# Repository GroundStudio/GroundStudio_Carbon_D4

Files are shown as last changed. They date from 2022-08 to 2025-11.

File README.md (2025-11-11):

GroundStudio Carbon D4
====================================
CarbonD4 cropat la 150 h (https://ardushop.ro/ro/home/2059-placa-de-dezvoltare-carbon-d4.html)

Get it from [ardushop.ro](https://ardushop.ro/en/electronics/1186-placa-de-dezvoltare-carbon-d4-6427854000408.html)

Explore all the GroundStudio products at [ardushop.ro](https://ardushop.ro/en/37-groundstudio)

Description
-------------------
Features ESP32 based Pico D4 SiP with 2.4GHz Wifi, V4.2 Bluetooth, 8MB external SPI PSRAM, 520kB internal SRAM, 448kB ROM, 14 GPIO, 8 ADC and 6 touch sensitive pins, I²C 3V3 adapter, RGB smart LED, 1 cell LiPo/LiIon battery charger with optional battery connector and CH340C for USB comunication.

Contents
-------------------

* [/Documentation](https://github.com/GroundStudio/GroundStudio_Carbon_D4/tree/main/Documentation) -- Pinout.
* [/Hardware](https://github.com/GroundStudio/GroundStudio_Carbon_D4/tree/main/Hardware) -- Schematics, layout.

Versions
-------------------
*(Not all tags shown)*

* [REV0.0.2]
  * added testpoint for GPIO0
  * R16 and R17 connected in series
  * interchanged GPIO2 and GPIO12 functions because GPIO12 cannot be pulled high while in flash mode
  * added 100nF in parallel with R13 for better battery voltage level reading
  * adjusted the pin labels for better visibility

License
-------------------

This is released under the [Attribution-ShareAlike 4.0 International (CC BY-SA 4.0)](https://creativecommons.org/licenses/by-sa/4.0/) license. 
**You are welcome to use this for commercial purposes.**

Please consider contributing back to this project or others to help the open-source hardware community continue to thrive and grow! 

Certifications:

[Open Source Hardware Association](https://certification.oshwa.org/ro000006.html)   
   
certification-mark-RO000006-wide (https://certification.oshwa.org/ro000006.html)

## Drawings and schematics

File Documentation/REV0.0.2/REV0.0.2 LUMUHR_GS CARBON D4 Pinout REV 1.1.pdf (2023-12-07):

# GroundStudio Carbon D4

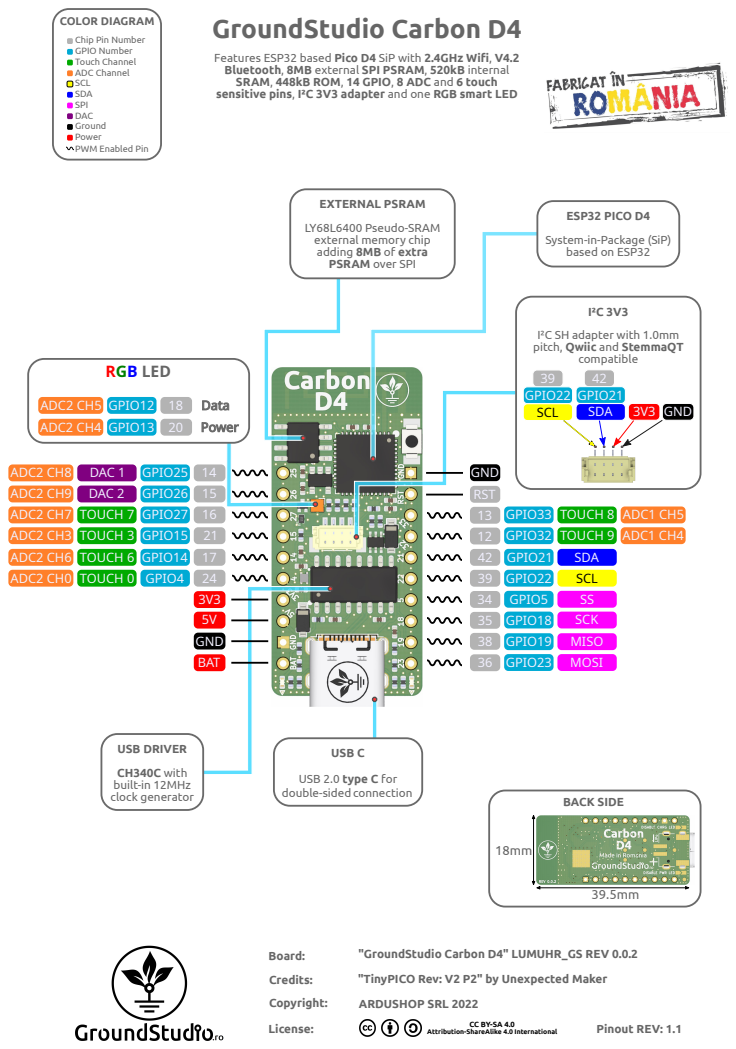
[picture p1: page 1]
COLOR DIAGRAM; GND RST 13 12 42 39 34 35 38 36; GPIO33 GPIO32 GPIO21 GPIO22 GPIO5 GPIO18 GPIO19 GPIO23; TOUCH 8 TOUCH 9 SDA SCL SS SCK MISO MOSI; ADC1 CH5 ADC1 CH4; USB DRIVER; CH340C with built-in 12MHz clock generator; GND BAT; GPIO25 GPIO26 GPIO27 GPIO15 GPIO14; DAC 1 DAC 2 TOUCH 7 TOUCH 3 TOUCH 6; ADC2 CH8 ADC2 CH9 ADC2 CH7 ADC2 CH3 ADC2 CH6; RGB LED; Data Power; ADC2 CH5 GPIO12 18 ADC2 CH4 GPIO13 20; ADC2 CH0 TOUCH 0 GPIO4 24; GND; SCL; I²C 3V3; compatible; USB C; BACK SIDE; Copyright: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

Chip Pin Number
GPIO Number
Touch Channel
ADC Channel
SCL
SDA
SPI
DAC
Ground
Power
PWM Enabled Pin

Features ESP32 based Pico D4 SiP with 2.4GHz Wifi, V4.2
Bluetooth, 8MB external SPI PSRAM, 520kB internal
SRAM, 448kB ROM, 14 GPIO, 8 ADC and 6 touch
sensitive pins, I²C 3V3 adapter and one RGB smart LED

EXTERNAL PSRAM
LY68L6400 Pseudo-SRAM
external memory chip
adding 8MB of extra
PSRAM over SPI

ESP32 PICO D4
System-in-Package (SiP)
based on ESP32

I²C SH adapter with 1.0mm
pitch, Qwiic and StemmaQT
GPIO21
GPIO22

USB 2.0 type C for
double-sided connection

"GroundStudio Carbon D4" LUMUHR_GS REV 0.0.2

Attribution-ShareAlike 4.0 International

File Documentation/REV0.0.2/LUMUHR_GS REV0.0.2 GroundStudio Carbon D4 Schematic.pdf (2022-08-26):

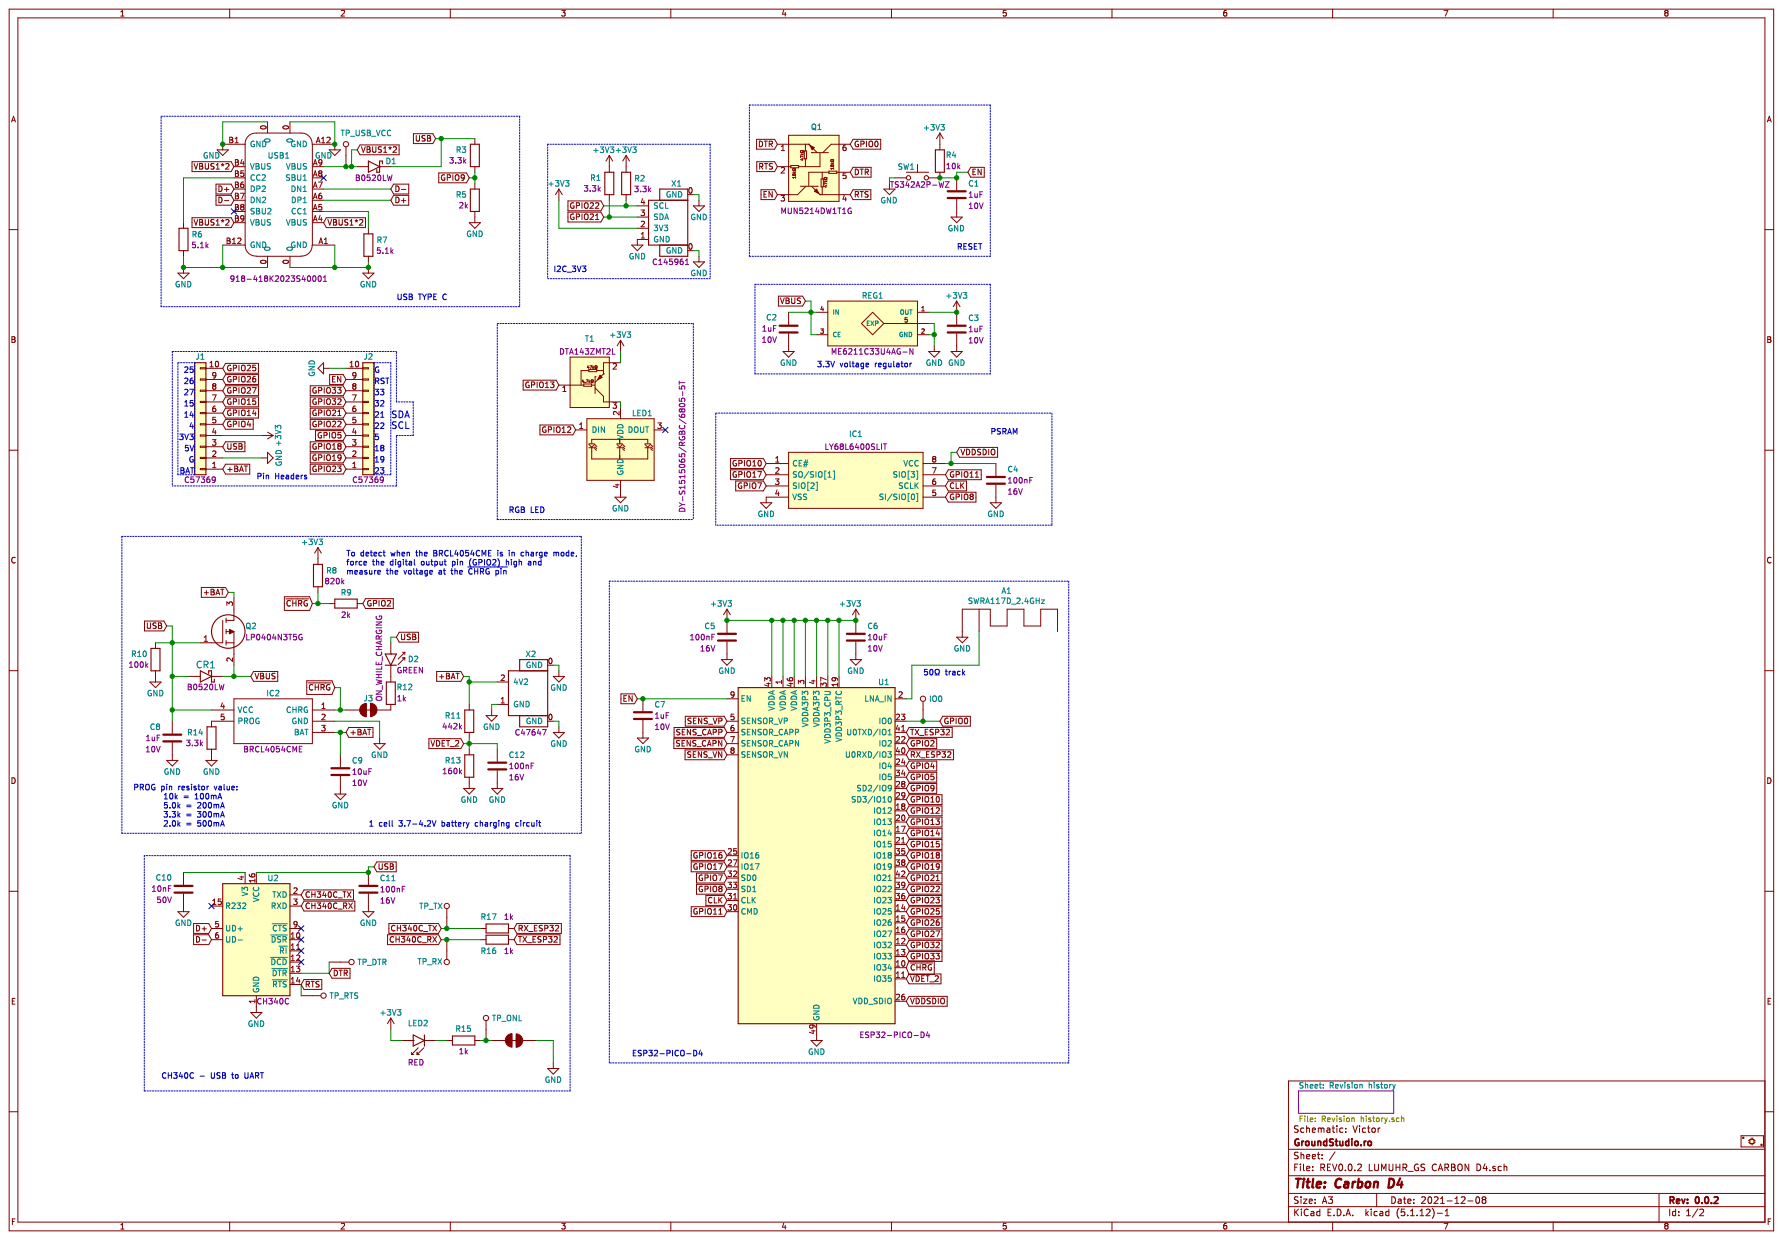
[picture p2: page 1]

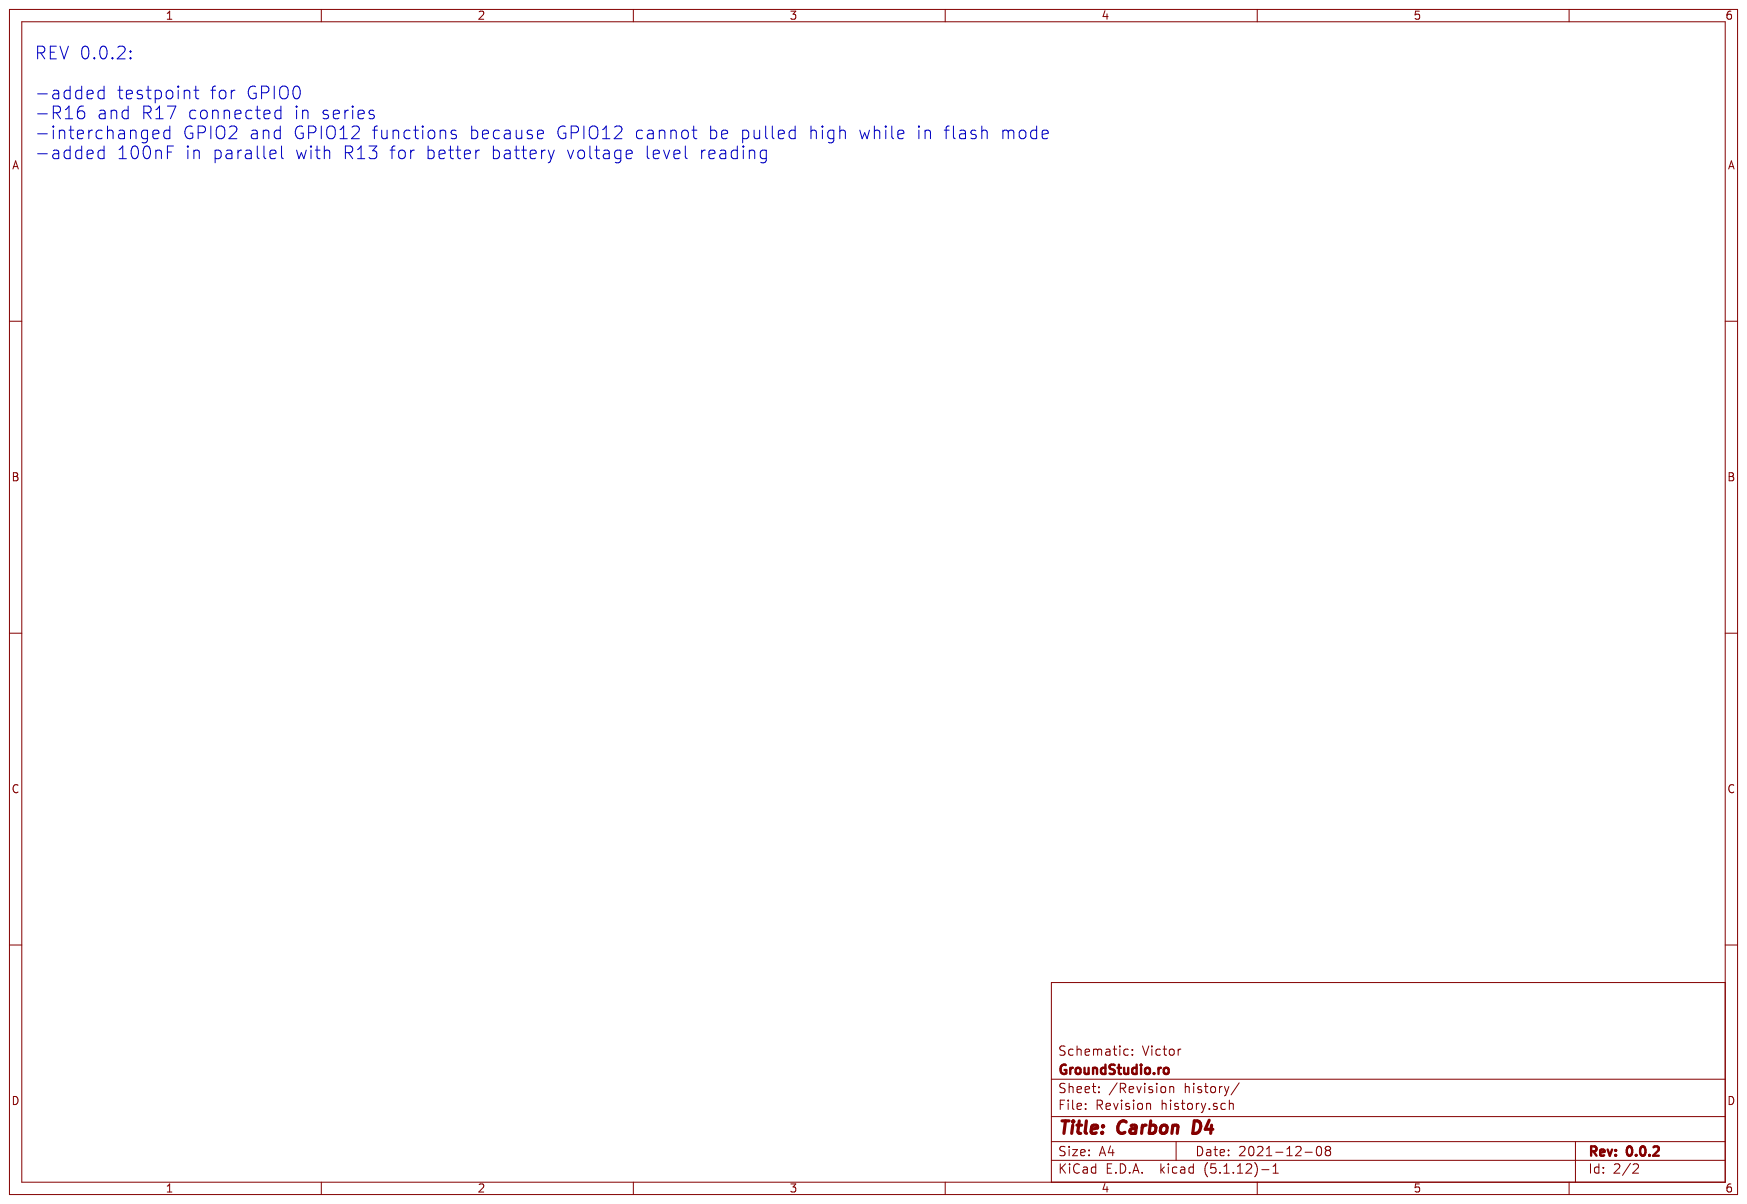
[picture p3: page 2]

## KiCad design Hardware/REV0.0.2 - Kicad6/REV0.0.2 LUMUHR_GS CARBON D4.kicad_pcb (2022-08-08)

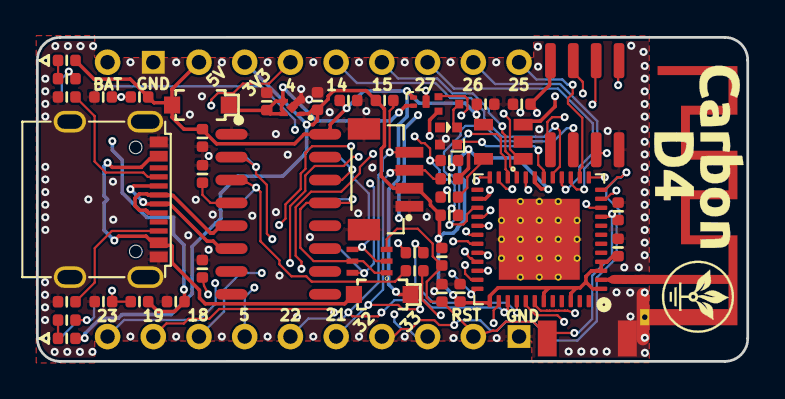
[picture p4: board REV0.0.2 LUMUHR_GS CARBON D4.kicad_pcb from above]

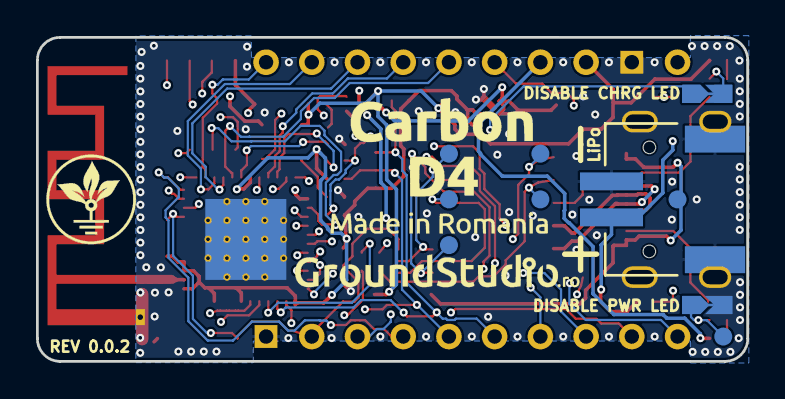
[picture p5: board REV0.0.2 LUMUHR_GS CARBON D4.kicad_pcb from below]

Board: 4 copper layers, 39.5 x 18.0 mm, 58 parts (5 on the bottom side), 53 nets.

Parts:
A1: SWRA117D_2.4GHz; Texas_SWRA117D_2.4GHz_Left
C1, C2, C3, C7, C8: C_0402_1uF_10V; C_0402_alt
C4, C5, C11, C12: C_0402_100nF_16V; C_0402_alt
C6, C9: C_0402_10uF_10V; C_0402_alt
C10: C_0402_10nF_50V; C_0402_alt
CR1: SOD-123 B0520LW; SOD-123
D1: SOD-123 B0520LW; SOD-123
D2: LED_0402_GREEN; LED_0402_alt
IC1: SOIC-8_3.9x4.9 LY68L6400SLIT; SOIC-8_3.9x4.9mm_P1.27mm
IC2: SOT23-5 BRCL4054CME; SOT-23-5
J1, J2: PinHeader_1x10_P2.54_V_M C57369; PinHeader_1x10_P2.54mm_Vertical_Male
J3: disable CHARGING LED; SolderJumper_NC
J4: PWR LED DISABLE; SolderJumper_NC
LED1: SK6805-EC15 DY-S1515065; SK6805-EC15
LED2: LED_0402_RED; LED_0402_alt
Q1: SOT-363 MUN5214DW1T1G; SOT-363
Q2: SOT-883 LP0404N3T5G; SOT-883
R1, R2, R3, R14: R_0402_3.3k; R_0402_alt
R4: R_0402_alt 0402WGJ0103TCE; R_0402_alt
R5, R9: R_0402_2k; R_0402_alt
R6, R7: R_0402_5.1k; R_0402_alt
R8: R_0402_820k; R_0402_alt
R10: R_0402_100k; R_0402_alt
R11: R_0402_442k; R_0402_alt
R12, R15, R16, R17: R_0402_1k; R_0402_alt
R13: R_0402_160k; R_0402_alt
REG1: FBP1-1-4_ME6211C33U4AG-N; FBP1-1-4
SW1: TS342A2P-WZ
T1: SOT-723_DTA143ZMT2L; SOT-723
TP1: TP_USB_VCC; TestPoint
TP2: TP_DTR; TestPoint
TP3: TP_TX; TestPoint
TP4: TP_RTS; TestPoint
TP5: TP_ONL; TestPoint
TP6: TP_RX; TestPoint
TP7: IO0; TestPoint
U1: QFN-48-7x7 ESP32-D4; QFN-48-1EP_7x7mm_P0.5mm_EP4.5x4.5mm
U2: SOP-16_150MIL CH340C; SOP-16_150MIL
USB1: USB_C_C167321 C167321; USB_C_C167321
X1: SH__1x04_Vertical C145961; SH__1x04_P1.00mm_Vertical
X2: PH__1x02_P2.00mm_Horizontal C47647; PH__1x02_P2.00mm_Horizontal

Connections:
+3V3: C3.1, C5.1, C6.1, J1.4, LED2.2, R1.2, R2.1, R4.2, R8.1, REG1.1, T1.2, U1.1, U1.3, U1.4, U1.19, U1.37, U1.43, U1.46, X1.2
+BAT: C9.1, IC2.3, J1.1, Q2.3, R11.2, X2.2
CH340C_RX: R16.1, TP6.~, U2.3
CH340C_TX: R17.1, TP3.~, U2.2
CLK: IC1.6, U1.31
D+: U2.5, USB1.A6, USB1.B6
D-: U2.6, USB1.A7, USB1.B7
DTR: Q1.1, Q1.5, TP2.~, U2.13
EN: C1.1, C7.1, J2.9, Q1.3, R4.1, SW1.2, U1.9
Feed: A1.1, U1.2
GND: A1.2, C1.2, C2.1, C3.2, C4.2, C5.2, C6.2, C7.2, C8.2, C9.2, C10.1, C11.2, C12.2, IC1.4, IC2.2, J1.2, J2.10, J4.2, LED1.4, R5.1, R6.2, R7.2, R10.1, R13.1, R14.1, REG1.2, REG1.5, SW1.1, U1.49, U2.1, USB1.0, USB1.A1, USB1.A12, USB1.B1, USB1.B12, X1.0, X1.1, X2.0, X2.1
GPIO0: Q1.6, TP7.~, U1.23
GPIO2: R9.2, U1.22
GPIO4: J1.5, U1.24
GPIO5: J2.4, U1.34
GPIO7: IC1.3, U1.32
GPIO8: IC1.5, U1.33
GPIO9: R3.1, R5.2, U1.28
GPIO10: IC1.1, U1.29
GPIO11: IC1.7, U1.30
GPIO12: LED1.1, U1.18
GPIO13: T1.1, U1.20
GPIO14: J1.6, U1.17
GPIO15: J1.7, U1.21
GPIO17: IC1.2, U1.27
GPIO18: J2.3, U1.35
GPIO19: J2.2, U1.38
GPIO21: J2.6, R1.1, U1.42, X1.3
GPIO22: J2.5, R2.2, U1.39, X1.4
GPIO23: J2.1, U1.36
GPIO25: J1.10, U1.14
GPIO26: J1.9, U1.15
GPIO27: J1.8, U1.16
GPIO32: J2.7, U1.12
GPIO33: J2.8, U1.13
unnamed: C10.2, U2.4
unnamed: D2.1, R12.2
unnamed: IC2.5, R14.2
unnamed: J3.2, R12.1
unnamed: J4.1, R15.2, TP5.~
unnamed: LED1.2, T1.3
unnamed: LED2.1, R15.1
unnamed: R6.1, USB1.B5
unnamed: R7.1, USB1.A5
RTS: Q1.2, Q1.4, TP4.~, U2.14
RX_ESP32: R17.2, U1.40
TX_ESP32: R16.2, U1.41
USB: C8.1, C11.1, CR1.2, D1.1, D2.2, IC2.4, J1.3, Q2.1, R3.2, R10.2, U2.16
VBUS: C2.2, CR1.1, Q2.2, REG1.3, REG1.4
VBUS1*2: D1.2, TP1.~, USB1.A4, USB1.A9, USB1.B4, USB1.B9
VDDSDIO: C4.1, IC1.8, U1.26
VDET_2: C12.1, R11.1, R13.2, U1.11
~CHRG: IC2.1, J3.1, R8.2, R9.1, U1.10

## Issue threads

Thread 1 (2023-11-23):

Question: How to measure battery voltage

alexandru-g, 2023-11-23:
Hello! Is there any way we can measure the connected cell's voltage / state of charge? Thank you!

victor1115, 2023-12-21:
Hi Alexandru,

Cell's voltage can be read using IO35 pin of the ESP32-PICO-D4.
The analog value need to be calibrated to consider the voltage divider between +BAT and GND so that it show the right voltage.

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

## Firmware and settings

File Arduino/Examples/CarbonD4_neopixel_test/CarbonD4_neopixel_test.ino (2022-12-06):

// A basic everyday NeoPixel strip test program.

// NEOPIXEL BEST PRACTICES for most reliable operation:
// - Add 1000 uF CAPACITOR between NeoPixel strip's + and - connections.
// - MINIMIZE WIRING LENGTH between microcontroller board and first pixel.
// - NeoPixel strip's DATA-IN should pass through a 300-500 OHM RESISTOR.
// - AVOID connecting NeoPixels on a LIVE CIRCUIT. If you must, ALWAYS
//   connect GROUND (-) first, then +, then data.
// - When using a 3.3V microcontroller with a 5V-powered NeoPixel strip,
//   a LOGIC-LEVEL CONVERTER on the data line is STRONGLY RECOMMENDED.
// (Skipping these may work OK on your workbench but can fail in the field)

#include <Adafruit_NeoPixel.h>
#ifdef __AVR__
 #include <avr/power.h> // Required for 16 MHz Adafruit Trinket
#endif

// Which pin on the Arduino is connected to the NeoPixels?
// On a Trinket or Gemma we suggest changing this to 1:
#define LED_PIN    12
#define LED_ENABLE_PIN 13

// How many NeoPixels are attached to the Arduino?
#define LED_COUNT 1

// Declare our NeoPixel strip object:
Adafruit_NeoPixel strip(LED_COUNT, LED_PIN, NEO_GRB + NEO_KHZ800);
// Argument 1 = Number of pixels in NeoPixel strip
// Argument 2 = Arduino pin number (most are valid)
// Argument 3 = Pixel type flags, add together as needed:
//   NEO_KHZ800  800 KHz bitstream (most NeoPixel products w/WS2812 LEDs)
//   NEO_KHZ400  400 KHz (classic 'v1' (not v2) FLORA pixels, WS2811 drivers)
//   NEO_GRB     Pixels are wired for GRB bitstream (most NeoPixel products)
//   NEO_RGB     Pixels are wired for RGB bitstream (v1 FLORA pixels, not v2)
//   NEO_RGBW    Pixels are wired for RGBW bitstream (NeoPixel RGBW products)


// setup() function -- runs once at startup --------------------------------

void setup() {
  pinMode(LED_ENABLE_PIN, OUTPUT);
  digitalWrite(LED_ENABLE_PIN, 0);
  // These lines are specifically to support the Adafruit Trinket 5V 16 MHz.
  // Any other board, you can remove this part (but no harm leaving it):
#if defined(__AVR_ATtiny85__) && (F_CPU == 16000000)
  clock_prescale_set(clock_div_1);
#endif
  // END of Trinket-specific code.

  strip.begin();           // INITIALIZE NeoPixel strip object (REQUIRED)
  strip.show();            // Turn OFF all pixels ASAP
  strip.setBrightness(50); // Set BRIGHTNESS to about 1/5 (max = 255)
}


// loop() function -- runs repeatedly as long as board is on ---------------

void loop() {
  // Fill along the length of the strip in various colors...
  colorWipe(strip.Color(255,   0,   0), 50); // Red
  colorWipe(strip.Color(  0, 255,   0), 50); // Green
  colorWipe(strip.Color(  0,   0, 255), 50); // Blue

  // Do a theater marquee effect in various colors...
  theaterChase(strip.Color(127, 127, 127), 50); // White, half brightness
  theaterChase(strip.Color(127,   0,   0), 50); // Red, half brightness
  theaterChase(strip.Color(  0,   0, 127), 50); // Blue, half brightness

  rainbow(10);             // Flowing rainbow cycle along the whole strip
  theaterChaseRainbow(50); // Rainbow-enhanced theaterChase variant
}


// Some functions of our own for creating animated effects -----------------

// Fill strip pixels one after another with a color. Strip is NOT cleared
// first; anything there will be covered pixel by pixel. Pass in color
// (as a single 'packed' 32-bit value, which you can get by calling
// strip.Color(red, green, blue) as shown in the loop() function above),
// and a delay time (in milliseconds) between pixels.
void colorWipe(uint32_t color, int wait) {
  for(int i=0; i<strip.numPixels(); i++) { // For each pixel in strip...
    strip.setPixelColor(i, color);         //  Set pixel's color (in RAM)
    strip.show();                          //  Update strip to match
    delay(wait);                           //  Pause for a moment
  }
}

// Theater-marquee-style chasing lights. Pass in a color (32-bit value,
// a la strip.Color(r,g,b) as mentioned above), and a delay time (in ms)
// between frames.
void theaterChase(uint32_t color, int wait) {
  for(int a=0; a<10; a++) {  // Repeat 10 times...
    for(int b=0; b<3; b++) { //  'b' counts from 0 to 2...
      strip.clear();         //   Set all pixels in RAM to 0 (off)
      // 'c' counts up from 'b' to end of strip in steps of 3...
      for(int c=b; c<strip.numPixels(); c += 3) {
        strip.setPixelColor(c, color); // Set pixel 'c' to value 'color'
      }
      strip.show(); // Update strip with new contents
      delay(wait);  // Pause for a moment
    }
  }
}

// Rainbow cycle along whole strip. Pass delay time (in ms) between frames.
void rainbow(int wait) {
  // Hue of first pixel runs 5 complete loops through the color wheel.
  // Color wheel has a range of 65536 but it's OK if we roll over, so
  // just count from 0 to 5*65536. Adding 256 to firstPixelHue each time
  // means we'll make 5*65536/256 = 1280 passes through this outer loop:
  for(long firstPixelHue = 0; firstPixelHue < 5*65536; firstPixelHue += 256) {
    for(int i=0; i<strip.numPixels(); i++) { // For each pixel in strip...
      // Offset pixel hue by an amount to make one full revolution of the
      // color wheel (range of 65536) along the length of the strip
      // (strip.numPixels() steps):
      int pixelHue = firstPixelHue + (i * 65536L / strip.numPixels());
      // strip.ColorHSV() can take 1 or 3 arguments: a hue (0 to 65535) or
      // optionally add saturation and value (brightness) (each 0 to 255).
      // Here we're using just the single-argument hue variant. The result
      // is passed through strip.gamma32() to provide 'truer' colors
      // before assigning to each pixel:
      strip.setPixelColor(i, strip.gamma32(strip.ColorHSV(pixelHue)));
    }
    strip.show(); // Update strip with new contents
    delay(wait);  // Pause for a moment
  }
}

// Rainbow-enhanced theater marquee. Pass delay time (in ms) between frames.
void theaterChaseRainbow(int wait) {
  int firstPixelHue = 0;     // First pixel starts at red (hue 0)
  for(int a=0; a<30; a++) {  // Repeat 30 times...
    for(int b=0; b<3; b++) { //  'b' counts from 0 to 2...
      strip.clear();         //   Set all pixels in RAM to 0 (off)
      // 'c' counts up from 'b' to end of strip in increments of 3...
      for(int c=b; c<strip.numPixels(); c += 3) {
        // hue of pixel 'c' is offset by an amount to make one full
        // revolution of the color wheel (range 65536) along the length
        // of the strip (strip.numPixels() steps):
        int      hue   = firstPixelHue + c * 65536L / strip.numPixels();
        uint32_t color = strip.gamma32(strip.ColorHSV(hue)); // hue -> RGB
        strip.setPixelColor(c, color); // Set pixel 'c' to value 'color'
      }
      strip.show();                // Update strip with new contents
      delay(wait);                 // Pause for a moment
      firstPixelHue += 65536 / 90; // One cycle of color wheel over 90 frames
    }
  }
}

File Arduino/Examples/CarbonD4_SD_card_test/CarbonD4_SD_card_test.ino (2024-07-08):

#include "FS.h"
#include "SD.h"
#include "SPI.h"

SPIClass spiSD;

#define SD_CS 5

void writeFile(fs::FS &fs, const char * path, const char * message){
    Serial.printf("Writing file: %s\n", path);

    File file = fs.open(path, FILE_WRITE);
    if(!file){
        Serial.println("Failed to open file for writing");
        return;
    }
    if(file.print(message)){
        Serial.println("File written");
    } else {
        Serial.println("Write failed");
    }
    file.close();
}

void setup()
{
  Serial.begin(9600);
  while (!Serial) delay(100);
  Serial.println();
  SPI.end(); 
  spiSD.begin(18, 19, 23, SD_CS); //CLK,MISO,MOSI,SS
  if (!SD.begin(SD_CS, spiSD))
  {
    Serial.println("Card Mount Failed");
    return;
  }
  else
  {
    Serial.println("Card Mount Successful");
  }

  uint8_t cardType = SD.cardType();

  Serial.print("SD Card Type: ");
  if(cardType == CARD_MMC){
        Serial.println("MMC");
    } else if(cardType == CARD_SD){
        Serial.println("SDSC");
    } else if(cardType == CARD_SDHC){
        Serial.println("SDHC");
    } else {
        Serial.println("UNKNOWN");
    }

    uint64_t cardSize = SD.cardSize() / (1024 * 1024);
    Serial.printf("SD Card Size: %lluMB\n", cardSize);
    
  writeFile(SD, "/hello D4.txt", "Hello D4");
  Serial.printf("Total space: %lluMB\n", SD.totalBytes() / (1024 * 1024));
  Serial.printf("Used space: %lluMB\n", SD.usedBytes() / (1024 * 1024));
}

void loop()
{ }

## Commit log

2022-08-08 - initial commit
    [REV0.0.2 LUMUHR_GS CARBON D4.kicad_pcb, REV0.0.2 LUMUHR_GS CARBON D4.kicad_sch, Revision history.kicad_sch]
2022-08-16 - added "Kicad6" to revision folder name
    [REV0.0.2 LUMUHR_GS CARBON D4.kicad_pcb, REV0.0.2 LUMUHR_GS CARBON D4.kicad_sch, Revision history.kicad_sch]
2022-08-26 - added schematic pdf file
2022-12-06 - added "Arduino" folder for code examples
2022-12-06 - added "CarbonD4_neopixel_test" Arduino example
2023-10-26 - added .step 3D file of the board
2024-07-08 - fixed pins order in spiSD.begin
    [CarbonD4_SD_card_test.ino]
